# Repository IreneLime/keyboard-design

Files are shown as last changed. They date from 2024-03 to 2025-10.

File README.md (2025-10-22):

This repo is the PCB design of an ergonomic keyboard.

Full Design:


PCB:


Firmware Code for this keyboard is located in: https://github.com/HWXLR8/qmk_firmware/tree/master/keyboards/irene

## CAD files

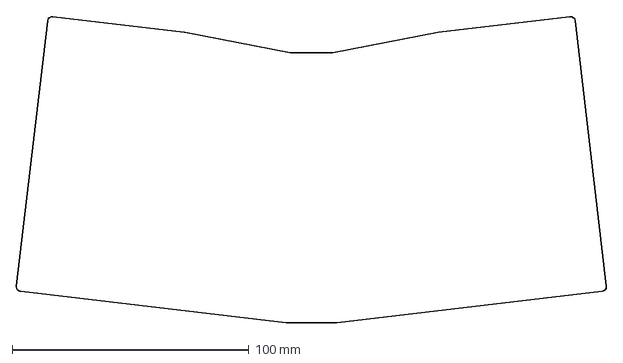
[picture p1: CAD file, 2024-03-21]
out/outlines/pcb_cutout.dxf
249.4 x 129.4 mm

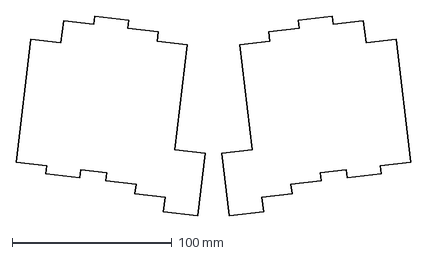
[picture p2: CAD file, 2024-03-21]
out/outlines/raw.dxf
246.7 x 124.8 mm

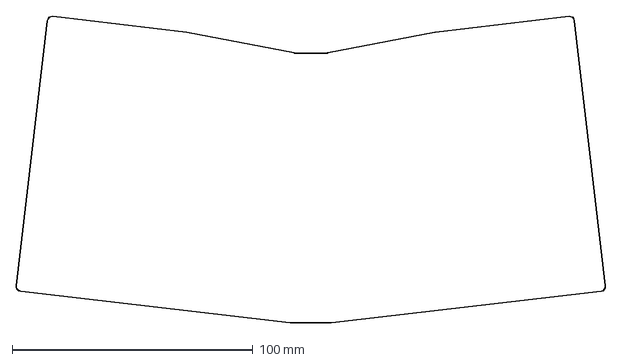
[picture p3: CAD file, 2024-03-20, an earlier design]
output/outlines/board.dxf
244.9 x 127.4 mm

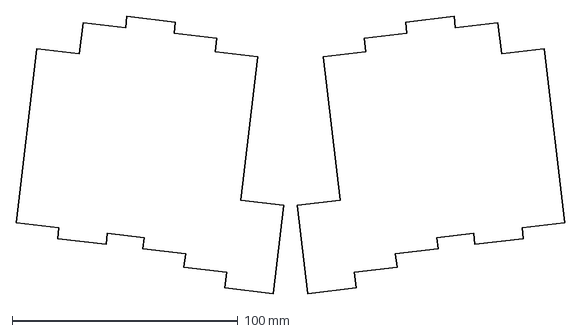
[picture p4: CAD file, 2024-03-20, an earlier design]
output/outlines/raw.dxf
242.8 x 122.8 mm

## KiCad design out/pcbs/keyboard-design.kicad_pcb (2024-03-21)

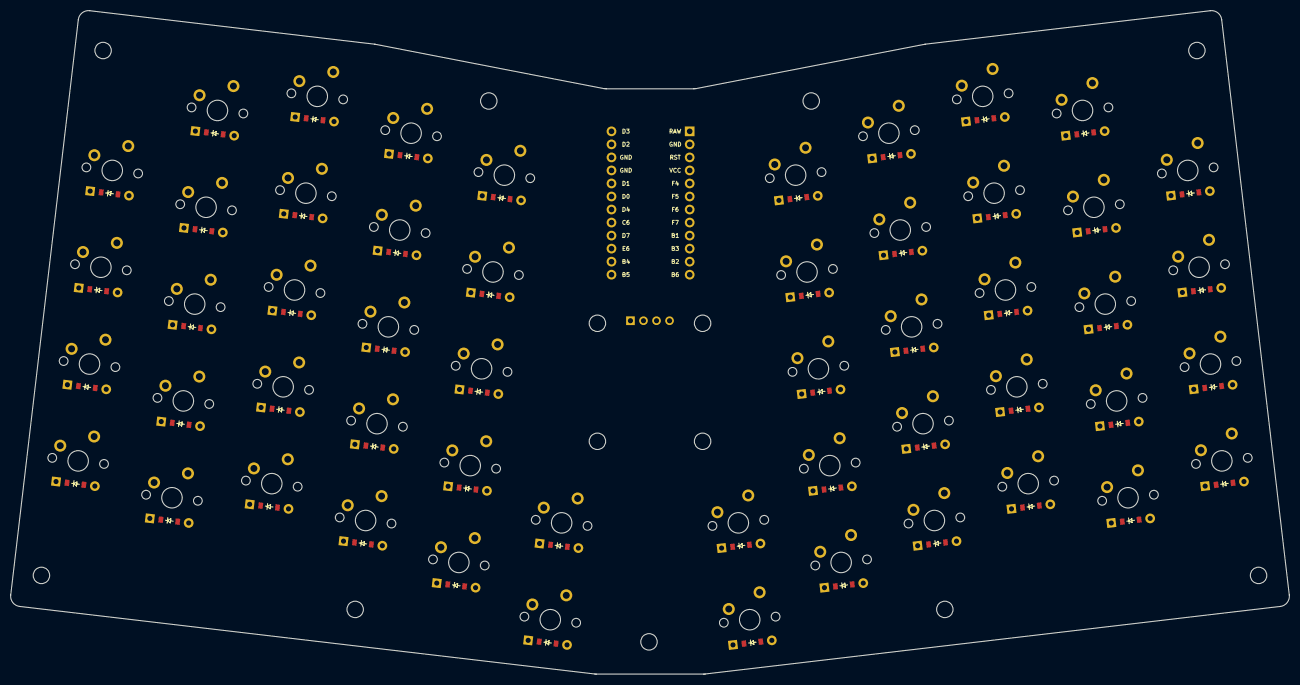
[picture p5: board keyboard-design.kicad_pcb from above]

Board: 2 copper layers, 249.2 x 129.3 mm, 106 parts (0 on the bottom side), 72 nets, no tracks yet.

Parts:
D1, D2, D3, D4, D5, D6, D7, D8, D9, D10, D11, D12, D13, D14, D15, D16, D17, D18, D19, D20, D21, D22, D23, D24, D25, D26, D27, D28, D29, D30, D31, D32, D33, D34, D35, D36, D37, D38, D39, D40, D41, D42, D43, D44, D45, D46, D47, D48, D49, D50, D51, D52: ComboDiode
MCU1: ProMicro
OLED1: OLED; OLED_headers
S1, S2, S3, S4, S5, S6, S7, S8, S9, S10, S11, S12, S13, S14, S15, S16, S17, S18, S19, S20, S21, S22, S23, S24, S25, S26, S27, S28, S29, S30, S31, S32, S33, S34, S35, S36, S37, S38, S39, S40, S41, S42, S43, S44, S45, S46, S47, S48, S49, S50, S51, S52: MX

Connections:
B1: MCU1.9, S47.2, S48.2, S49.2, S50.2, S51.2, S52.2
B2: D2.1, D7.1, D12.1, D17.1, D22.1, D28.1, D33.1, D38.1, D43.1, D48.1, MCU1.11
B3: D3.1, D8.1, D13.1, D18.1, D23.1, D29.1, D34.1, D39.1, D44.1, D49.1, MCU1.10
B4: D1.1, D6.1, D11.1, D16.1, D21.1, D27.1, D32.1, D37.1, D42.1, D47.1, MCU1.23
B5: D25.1, D51.1, MCU1.24
B6: D4.1, D9.1, D14.1, D19.1, D24.1, D30.1, D35.1, D40.1, D45.1, D50.1, MCU1.12
C6: MCU1.20, S16.2, S17.2, S18.2, S19.2, S20.2
D0: MCU1.18, OLED1.3
D1: MCU1.17, OLED1.4
D2: MCU1.14, S1.2, S2.2, S3.2, S4.2, S5.2
D3: MCU1.13, S6.2, S7.2, S8.2, S9.2, S10.2
D4: MCU1.19, S11.2, S12.2, S13.2, S14.2, S15.2
D7: MCU1.21, S21.2, S22.2, S23.2, S24.2, S25.2, S26.2
E6: D5.1, D10.1, D15.1, D20.1, D26.1, D31.1, D36.1, D41.1, D46.1, D52.1, MCU1.22
F4: MCU1.5, S27.2, S28.2, S29.2, S30.2, S31.2
F5: MCU1.6, S32.2, S33.2, S34.2, S35.2, S36.2
F6: MCU1.7, S37.2, S38.2, S39.2, S40.2, S41.2
F7: MCU1.8, S42.2, S43.2, S44.2, S45.2, S46.2
GND: MCU1.2, MCU1.15, MCU1.16, OLED1.1
VCC: MCU1.4, OLED1.2
index_bottom: D15.2, S15.1
index_home: D16.2, S16.1
index_mid: D17.2, S17.1
index_num: D19.2, S19.1
index_top: D18.2, S18.1
inner_bottom: D20.2, S20.1
inner_home: D21.2, S21.1
inner_mid: D22.2, S22.1
inner_num: D24.2, S24.1
inner_top: D23.2, S23.1
middle_bottom: D10.2, S10.1
middle_home: D11.2, S11.1
middle_mid: D12.2, S12.1
middle_num: D14.2, S14.1
middle_top: D13.2, S13.1
mirror_index_bottom: D41.2, S41.1
mirror_index_home: D42.2, S42.1
mirror_index_mid: D43.2, S43.1
mirror_index_num: D45.2, S45.1
mirror_index_top: D44.2, S44.1
mirror_inner_bottom: D46.2, S46.1
mirror_inner_home: D47.2, S47.1
mirror_inner_mid: D48.2, S48.1
mirror_inner_num: D50.2, S50.1
mirror_inner_top: D49.2, S49.1
mirror_middle_bottom: D36.2, S36.1
mirror_middle_home: D37.2, S37.1
mirror_middle_mid: D38.2, S38.1
mirror_middle_num: D40.2, S40.1
mirror_middle_top: D39.2, S39.1
mirror_pinky_home: D27.2, S27.1
mirror_pinky_mid: D28.2, S28.1
mirror_pinky_num: D30.2, S30.1
mirror_pinky_top: D29.2, S29.1
mirror_ring_bottom: D31.2, S31.1
mirror_ring_home: D32.2, S32.1
mirror_ring_mid: D33.2, S33.1
mirror_ring_num: D35.2, S35.1
mirror_ring_top: D34.2, S34.1
mirror_thumb_bottom: D52.2, S52.1
mirror_thumb_bottom_thumb: D51.2, S51.1
pinky_home: D1.2, S1.1
pinky_mid: D2.2, S2.1
pinky_num: D4.2, S4.1
pinky_top: D3.2, S3.1
ring_bottom: D5.2, S5.1
ring_home: D6.2, S6.1
ring_mid: D7.2, S7.1
ring_num: D9.2, S9.1
ring_top: D8.2, S8.1
thumb_bottom: D26.2, S26.1
thumb_bottom_thumb: D25.2, S25.1

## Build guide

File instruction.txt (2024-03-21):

git add submodule ...
git submodule init
git submodule update

In ergogen submodule:
npm install
make view

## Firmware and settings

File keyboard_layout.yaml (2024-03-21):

units:
  mm: 1
  kx: cx
  ky: cy
  px: kx + 2
  py: ky + 2

points:
  zones:
    matrix:
      columns:
        pinky:
          key:
            skip: false
            column_net: D2
            mirror.column_net: F4
          rows:
            bottom.skip: true
            bottom_thumb.skip: true
        ring:
          key:
            stagger: 14
            column_net: D3
            mirror.column_net: F5
          rows:
            bottom.column_net: D2
            bottom.mirror.column_net: F4
            bottom_thumb.skip: true
        middle:
          key:
            stagger: 5
            column_net: D4
            mirror.column_net: F6
          rows:
            bottom.column_net: D3
            bottom.mirror.column_net: F5
            bottom_thumb.skip: true
        index:
          key:
            stagger: -5
            column_net: C6
            mirror.column_net: F7
          rows:
            bottom.column_net: D4
            bottom.mirror.column_net: F6
            bottom_thumb.skip: true
        inner:
          key:
            stagger: -6
            column_net: D7
            mirror.column_net: B1
          rows:
            bottom.column_net: C6
            bottom.mirror.column_net: F7
            bottom_thumb.skip: true
        thumb:
          key:
            skip: true
            stagger: 10
            column_net: D7
            mirror.column_net: B1
          rows:
            bottom.skip: false
            bottom_thumb.skip: false
      rows:
        bottom_thumb:
          row_net: B5
        bottom:
          row_net: E6
        home:
          row_net: B4
        mid:
          row_net: B2
        top:
          row_net: B3
        num:
          row_net: B6

  rotate: -6.7
  mirror:
    ref: matrix_thumb_home
    distance: 30

outlines:
  raw:
    - what: rectangle
      where: true
      size: [1.2cx, 1.2cy]
  board:
    - what: polygon
      operation: stack
      fillet: 2
      points:
        - ref: matrix_middle_top
          shift: [-2.5px + 2, 1.6py]
        - ref: matrix_middle_top
          shift: [0.5px,1.6py]
        - ref: matrix_inner_top
          shift: [0.5px + 7.53, 2.0py]
        - ref: matrix_inner_top
          shift: [0.5px + 7.53, 2.0py]
        - ref: mirror_matrix_inner_top
          shift: [0.5px + 7.53, 2.0py]
        - ref: mirror_matrix_inner_top
          shift: [0.5px + 7.53, 2.0py]
        - ref: mirror_matrix_middle_top
          shift: [0.5px, 1.6py]
        - ref: mirror_matrix_middle_top
          shift: [-0.5px, 1.6py]
        - ref: mirror_matrix_middle_top
          shift: [-2.5px + 2, 1.6py]
        - ref: mirror_matrix_thumb_bottom_thumb
          shift: [-5.5px + 5,-0.5py]
        - ref: mirror_matrix_thumb_bottom_thumb
          shift: [-0.5px,-0.5py]
        - ref: mirror_matrix_thumb_bottom_thumb
          shift: [0.5px, -0.5py]
        - ref: matrix_thumb_bottom_thumb
          shift: [0.5px, -0.5py]
        - ref: matrix_thumb_bottom_thumb
          shift: [-0.5px, -0.5py]
        - ref: matrix_thumb_bottom_thumb
          shift: [-5.5px + 5,-0.5py]
  pcb_cutout:
    - what: outline
      name: board
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

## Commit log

2024-03-20 Update keyboard_layout.yaml fix border
    [keyboard_layout.yaml]
2024-03-21 Add mounting holes
    [board.dxf, keyboard-design.kicad_pcb, niu.kicad_pcb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]
2024-03-21 Finished mounting hole placement
    [keyboard-design.kicad_pcb]
2024-03-22 Added silkscreen & Make text invisible
2025-10-22 Update README.md
    Add PCB image
